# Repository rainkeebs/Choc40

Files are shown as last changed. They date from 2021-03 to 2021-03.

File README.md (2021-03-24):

# Choc40
*THIS IS UNTESTED*

These files were made in KiCad nightly. They are not backwards compatible.
40% Low profile keyboard designed for Kailh 'Choc' v1 switches and MBK Extended keycaps.







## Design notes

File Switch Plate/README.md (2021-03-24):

MUST be 1.2mm thick to work with Choc stabilizers



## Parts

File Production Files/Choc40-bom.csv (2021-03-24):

Designator | Qnty | Comment | Cmp name | Footprint | Description | LCSC Part Number
C1, | 1 | 1uF | C_Small | Capacitor_SMD:C_0603_1608Metric | Unpolarized capacitor, small symbol |  | C15849
C2, C3, | 2 | 0.1uF | C_Small | Capacitor_SMD:C_0603_1608Metric | Unpolarized capacitor, small symbol |  | C14663
C4, | 1 | 10uF | C_Small | Capacitor_SMD:C_0603_1608Metric | Unpolarized capacitor, small symbol |  | C19702
C5, | 1 | 4.7n | C_Small | Capacitor_SMD:C_0603_1608Metric | Unpolarized capacitor, small symbol |  | C53987
D1, D2, D3, D4, D5, D6, D7, D8, D9, D10, D11, D12, D13, D14, D15, D16, D17, D18, D19, D20, D21, D22, D23, D24, D25, D26, D27, D28, D29, D30, D31, D32, D33, D34, D35, D36, D37, D38, D39, D40, | 40 | D_Small | D_Small | Diode_SMD:D_SOD-123 | Diode, small symbol |  | C64898
D41, | 1 | PRTR5V0U2X | PRTR5V0U2X | Package_TO_SOT_SMD:SOT-143 | Ultra low capacitance double rail-to-rail ESD protection diode, SOT-363 |  | C384891
F1, | 1 | 500mA | Polyfuse_Small | Fuse:Fuse_1206_3216Metric | Resettable fuse, polymeric positive temperature coefficient, small symbol |  | C70076
R1, R4, | 2 | 10k | R_Small | Resistor_SMD:R_0603_1608Metric | Resistor, small symbol |  | C25804
R2, R3, | 2 | 22 | R_Small | Resistor_SMD:R_0603_1608Metric | Resistor, small symbol |  | C23345
R5, R6, | 2 | 5k1 | R_Small | Resistor_SMD:R_0603_1608Metric | Resistor, small symbol |  | C23186
R7, | 1 | 1M | R_Small | Resistor_SMD:R_0603_1608Metric | Resistor, small symbol |  | C22935
U1, | 1 | ATmega32U2-MU | ATmega32U2-MU | Package_DFN_QFN:QFN-32-1EP_5x5mm_P0.5mm_EP3.1x3.1mm | 16MHz, 32kB Flash, 1kB SRAM, 1kB EEPROM, QFN-32 |  | C57345
USB1, | 1 | HRO-TYPE-C-31-M-12 | HRO-TYPE-C-31-M-12 | Type-C:HRO-TYPE-C-31-M-12 |  |  | C165948
Y1, | 1 | Resonator_Small | Resonator_Small | Crystal:Resonator_SMD_muRata_CSTxExxV-3Pin_3.0x1.1mm | Three pin ceramic resonator, small symbol |  | C341521

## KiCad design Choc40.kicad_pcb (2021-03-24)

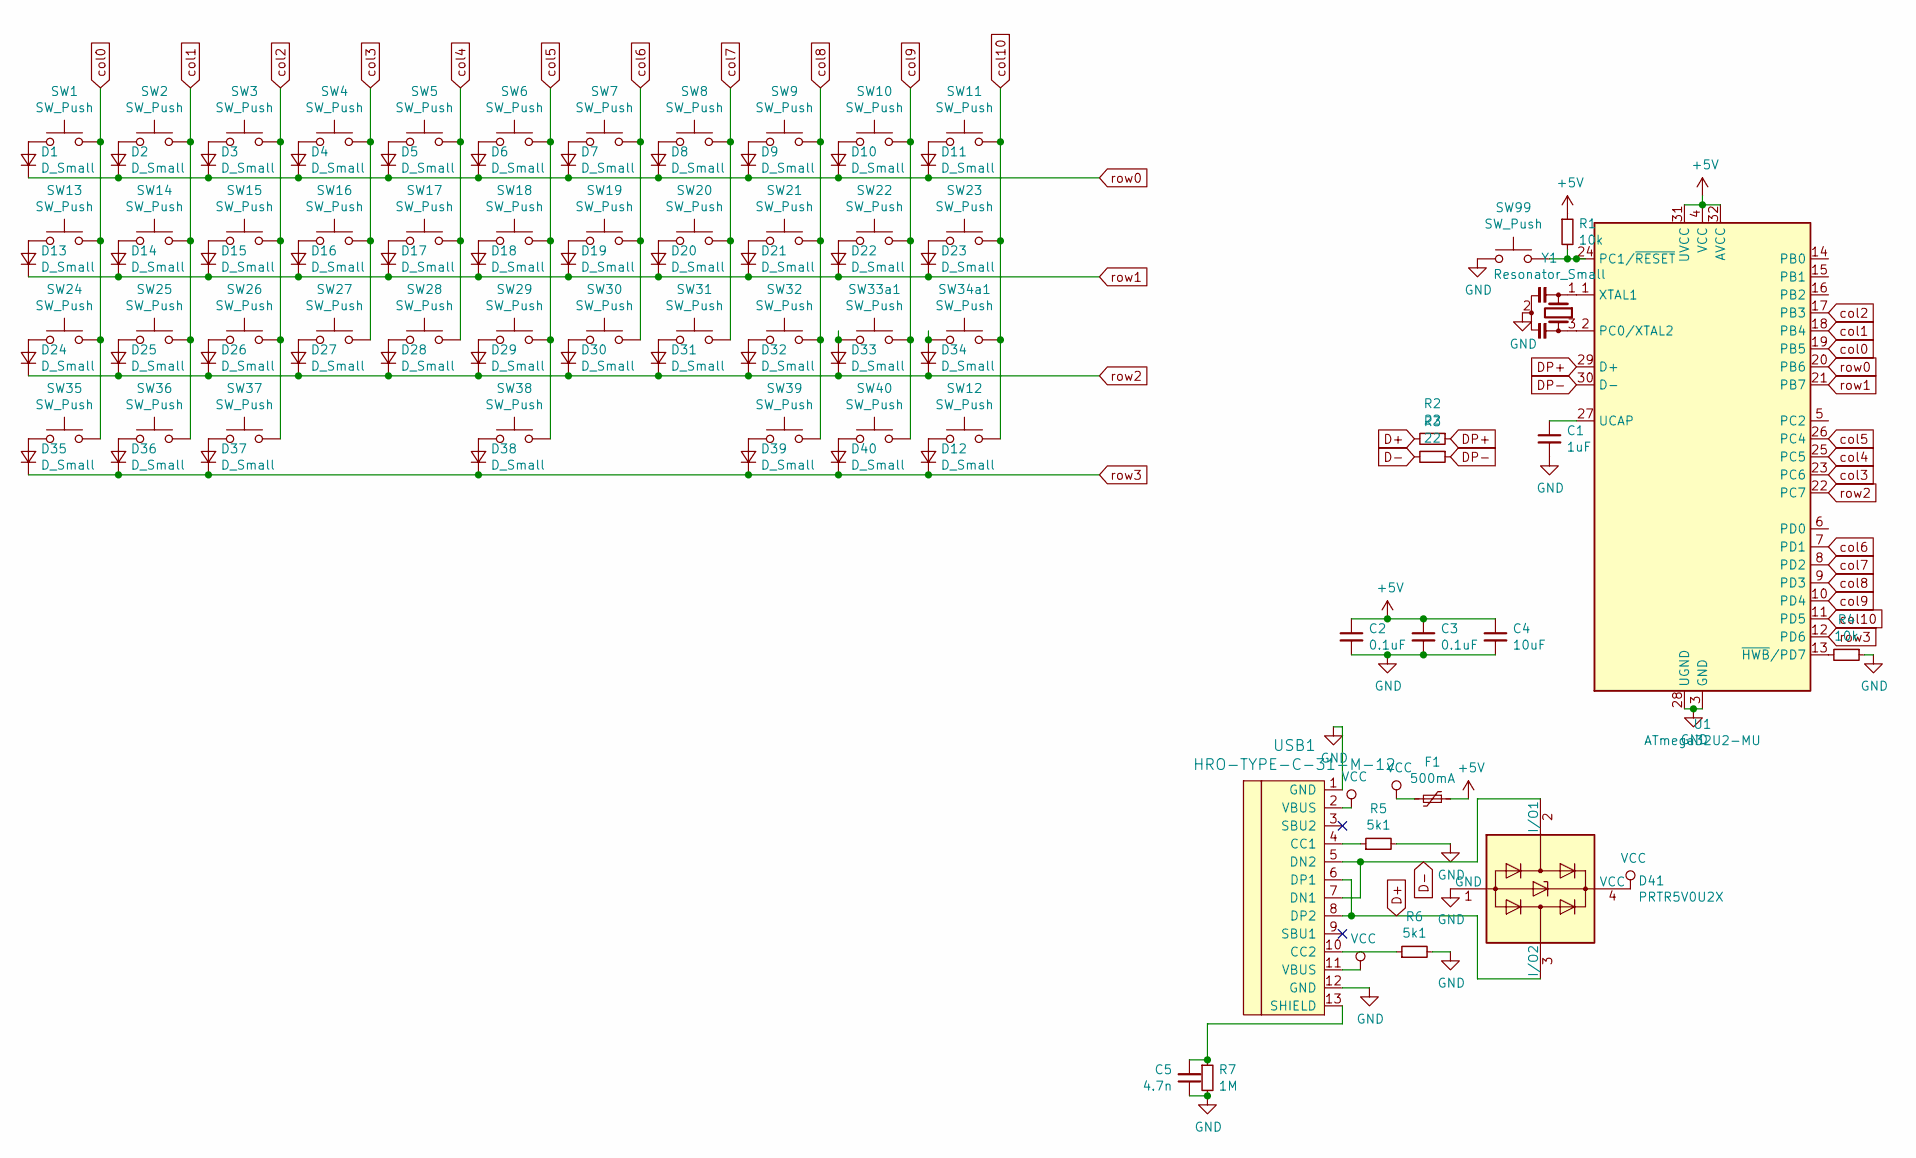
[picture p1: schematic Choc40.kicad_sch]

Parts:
C1: 1uF; C_0603_1608Metric
C2, C3: 0.1uF; C_0603_1608Metric
C4: 10uF; C_0603_1608Metric
C5: 4.7n; C_0603_1608Metric
D1, D2, D3, D4, D5, D6, D7, D8, D9, D10, D11, D12, D13, D14, D15, D16, D17, D18, D19, D20, D21, D22, D23, D24, D25, D26, D27, D28, D29, D30, D31, D32, D33, D34, D35, D36, D37, D38, D39, D40: D_Small; D_SOD-123
D41: PRTR5V0U2X; SOT-143
F1: 500mA; Fuse_1206_3216Metric
R1, R4: 10k; R_0603_1608Metric
R2, R3: 22; R_0603_1608Metric
R5, R6: 5k1; R_0603_1608Metric
R7: 1M; R_0603_1608Metric
SW1, SW2, SW3, SW4, SW5, SW6, SW7, SW8, SW9, SW10, SW11, SW12, SW14, SW15, SW16, SW17, SW18, SW19, SW20, SW21, SW22, SW25, SW26, SW27, SW28, SW29, SW30, SW31, SW32, SW33a1, SW36, SW37: SW_Push; Choc-1u-solder
SW13, SW34a1, SW35, SW39, SW40: SW_Push; Choc-1.25u-solder
SW23, SW24: SW_Push; Choc-1.75u-solder
SW38: SW_Push; Choc-6.25u-solder
SW99: SW_Push; SKQG-1155865
U1: ATmega32U2-MU; QFN-32-1EP_5x5mm_P0.5mm_EP3.1x3.1mm
USB1: HRO-TYPE-C-31-M-12
Y1: Resonator_Small; Resonator_SMD_muRata_CSTxExxV-3Pin_3.0x1.1mm

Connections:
+5V: C2.1, C3.1, C4.1, F1.1, R1.1, U1.4 (VCC), U1.31 (UVCC), U1.32 (AVCC)
D+: D41.3 (I/O2), R2.2, USB1.6 (DP1), USB1.8 (DP2)
D-: D41.2 (I/O1), R3.2, USB1.5 (DN2), USB1.7 (DN1)
DP+: R2.1, U1.29 (D+)
DP-: R3.1, U1.30 (D-)
GND: C1.2, C2.2, C3.2, C4.2, C5.1, D41.1 (GND), R4.1, R5.2, R6.2, R7.2, SW99.1, U1.3 (GND), U1.28 (UGND), U1.33 (GND), USB1.1 (GND), USB1.12 (GND), Y1.2
unnamed: C1.1, U1.27 (UCAP)
unnamed: C5.2, R7.1, USB1.13 (SHIELD)
unnamed: D1.2 (A), SW1.1
unnamed: D2.2 (A), SW2.1
unnamed: D3.2 (A), SW3.1
unnamed: D4.2 (A), SW4.1
unnamed: D5.2 (A), SW5.1
unnamed: D6.2 (A), SW6.1
unnamed: D7.2 (A), SW7.1
unnamed: D8.2 (A), SW8.1
unnamed: D9.2 (A), SW9.1
unnamed: D10.2 (A), SW10.1
unnamed: D11.2 (A), SW11.1
unnamed: D12.2 (A), SW12.1
unnamed: D13.2 (A), SW13.1
unnamed: D14.2 (A), SW14.1
unnamed: D15.2 (A), SW15.1
unnamed: D16.2 (A), SW16.1
unnamed: D17.2 (A), SW17.1
unnamed: D18.2 (A), SW18.1
unnamed: D19.2 (A), SW19.1
unnamed: D20.2 (A), SW20.1
unnamed: D21.2 (A), SW21.1
unnamed: D22.2 (A), SW22.1
unnamed: D23.2 (A), SW23.1
unnamed: D24.2 (A), SW24.1
unnamed: D25.2 (A), SW25.1
unnamed: D26.2 (A), SW26.1
unnamed: D27.2 (A), SW27.1
unnamed: D28.2 (A), SW28.1
unnamed: D29.2 (A), SW29.1
unnamed: D30.2 (A), SW30.1
unnamed: D31.2 (A), SW31.1
unnamed: D32.2 (A), SW32.1
unnamed: D33.2 (A), SW33a1.1
unnamed: D34.2 (A), SW34a1.1
unnamed: D35.2 (A), SW35.1
unnamed: D36.2 (A), SW36.1
unnamed: D37.2 (A), SW37.1
unnamed: D38.2 (A), SW38.1
unnamed: D39.2 (A), SW39.1
unnamed: D40.2 (A), SW40.1
unnamed: R1.2, SW99.2, U1.24 (PC1/~RESET)
unnamed: R4.2, U1.13 (~HWB~/PD7)
unnamed: R5.1, USB1.4 (CC1)
unnamed: R6.1, USB1.10 (CC2)
unnamed: U1.1 (XTAL1), Y1.1
unnamed: U1.2 (PC0/XTAL2), Y1.3
VCC: D41.4 (VCC), F1.2, USB1.2 (VBUS), USB1.11 (VBUS)
col0: SW1.2, SW13.2, SW24.2, SW35.2, U1.19 (PB5)
col1: SW2.2, SW14.2, SW25.2, SW36.2, U1.18 (PB4)
col2: SW3.2, SW15.2, SW26.2, SW37.2, U1.17 (PB3)
col3: SW4.2, SW16.2, SW27.2, U1.23 (PC6)
col4: SW5.2, SW17.2, SW28.2, U1.25 (PC5)
col5: SW6.2, SW18.2, SW29.2, SW38.2, U1.26 (PC4)
col6: SW7.2, SW19.2, SW30.2, U1.7 (PD1)
col7: SW8.2, SW20.2, SW31.2, U1.8 (PD2)
col8: SW9.2, SW21.2, SW32.2, SW39.2, U1.9 (PD3)
col9: SW10.2, SW22.2, SW33a1.2, SW40.2, U1.10 (PD4)
col10: SW11.2, SW12.2, SW23.2, SW34a1.2, U1.11 (PD5)
row0: D1.1 (K), D2.1 (K), D3.1 (K), D4.1 (K), D5.1 (K), D6.1 (K), D7.1 (K), D8.1 (K), D9.1 (K), D10.1 (K), D11.1 (K), U1.20 (PB6)
row1: D13.1 (K), D14.1 (K), D15.1 (K), D16.1 (K), D17.1 (K), D18.1 (K), D19.1 (K), D20.1 (K), D21.1 (K), D22.1 (K), D23.1 (K), U1.21 (PB7)
row2: D24.1 (K), D25.1 (K), D26.1 (K), D27.1 (K), D28.1 (K), D29.1 (K), D30.1 (K), D31.1 (K), D32.1 (K), D33.1 (K), D34.1 (K), U1.22 (PC7)
row3: D12.1 (K), D35.1 (K), D36.1 (K), D37.1 (K), D38.1 (K), D39.1 (K), D40.1 (K), U1.12 (PD6)

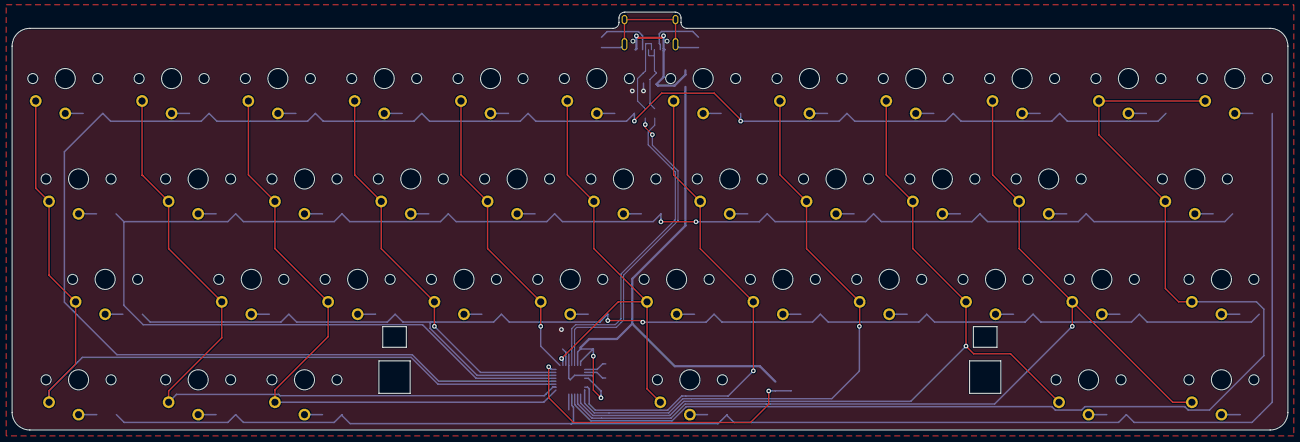
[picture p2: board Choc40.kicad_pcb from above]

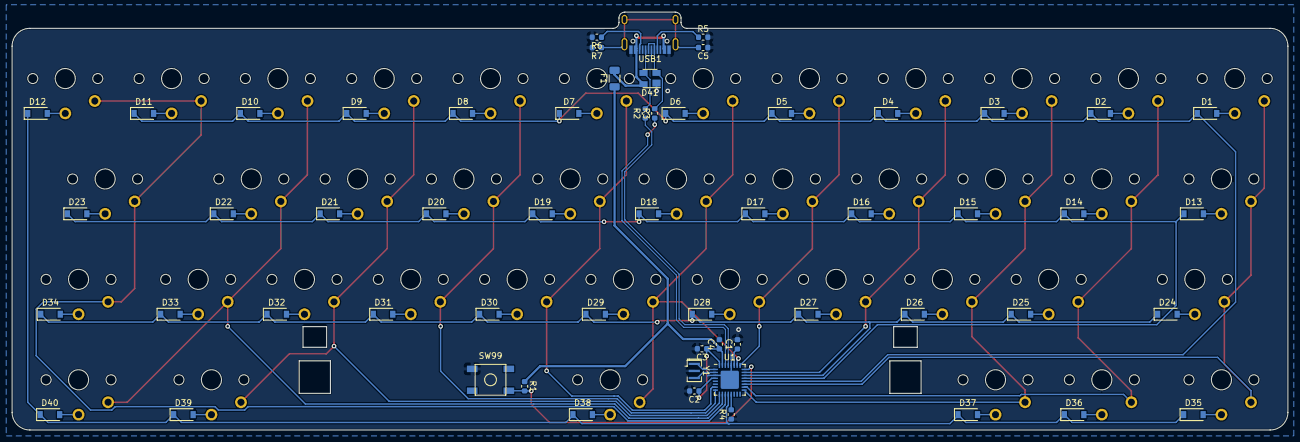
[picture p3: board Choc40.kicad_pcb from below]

Board: 2 copper layers, 216.0 x 70.8 mm, 98 parts (58 on the bottom side), 70 nets.

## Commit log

2021-03-22 Added Type C.pretty
    https://github.com/ai03-2725/Type-C.pretty.git
    [Choc40.kicad_sch]
2021-03-22 pcb go brr
    [Choc40.kicad_pcb]
2021-03-22 le epic progression
    [Choc40.kicad_pcb, Choc40.kicad_sch]
2021-03-23 PCB finished
    [Choc40.kicad_pcb]
2021-03-23 Schematic finished
    [Choc40.kicad_sch]
2021-03-24 switcvh plate
    [Choc40-switch_plate.kicad_pcb, Choc40-switch_plate.kicad_sch]
2021-03-24 Production files added
    [Choc40-B_Cu.gbr, Choc40-B_Fab.gbr, Choc40-B_Mask.gbr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]
2021-03-24 bom fix
    [Choc40-bom.csv]
